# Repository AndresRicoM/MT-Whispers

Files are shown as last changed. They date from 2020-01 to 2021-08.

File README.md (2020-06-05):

# MT-Whispers

```
███╗   ███╗████████╗    ██╗    ██╗██╗  ██╗██╗███████╗██████╗ ███████╗██████╗ ███████╗
████╗ ████║╚══██╔══╝    ██║    ██║██║  ██║██║██╔════╝██╔══██╗██╔════╝██╔══██╗██╔════╝
██╔████╔██║   ██║       ██║ █╗ ██║███████║██║███████╗██████╔╝█████╗  ██████╔╝███████╗
██║╚██╔╝██║   ██║       ██║███╗██║██╔══██║██║╚════██║██╔═══╝ ██╔══╝  ██╔══██╗╚════██║
██║ ╚═╝ ██║   ██║       ╚███╔███╔╝██║  ██║██║███████║██║     ███████╗██║  ██║███████║
╚═╝     ╚═╝   ╚═╝        ╚══╝╚══╝ ╚═╝  ╚═╝╚═╝╚══════╝╚═╝     ╚══════╝╚═╝  ╚═╝╚══════╝
```

Mountain vitals is a project that experiments with a variety of sensors to understand mountain conditions. The project is part of the MIT Media Lab's (City Science Group) collaboration with the country of Andorra.

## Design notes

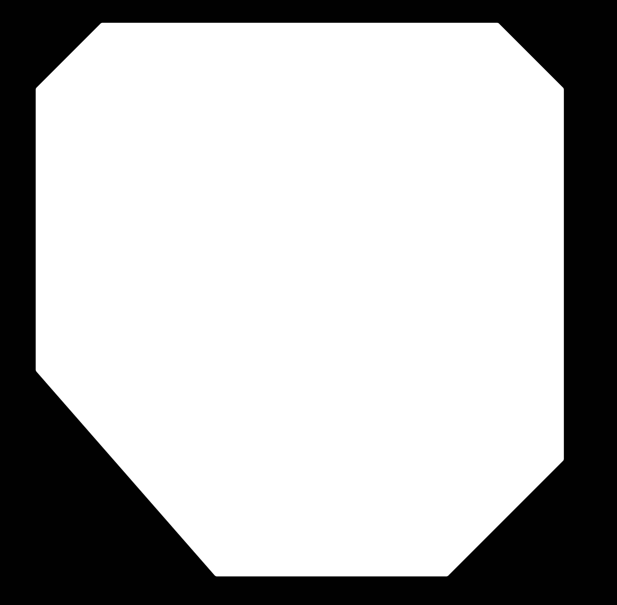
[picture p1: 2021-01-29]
board_production_files/ski-control-v1/ski-control-outline.png

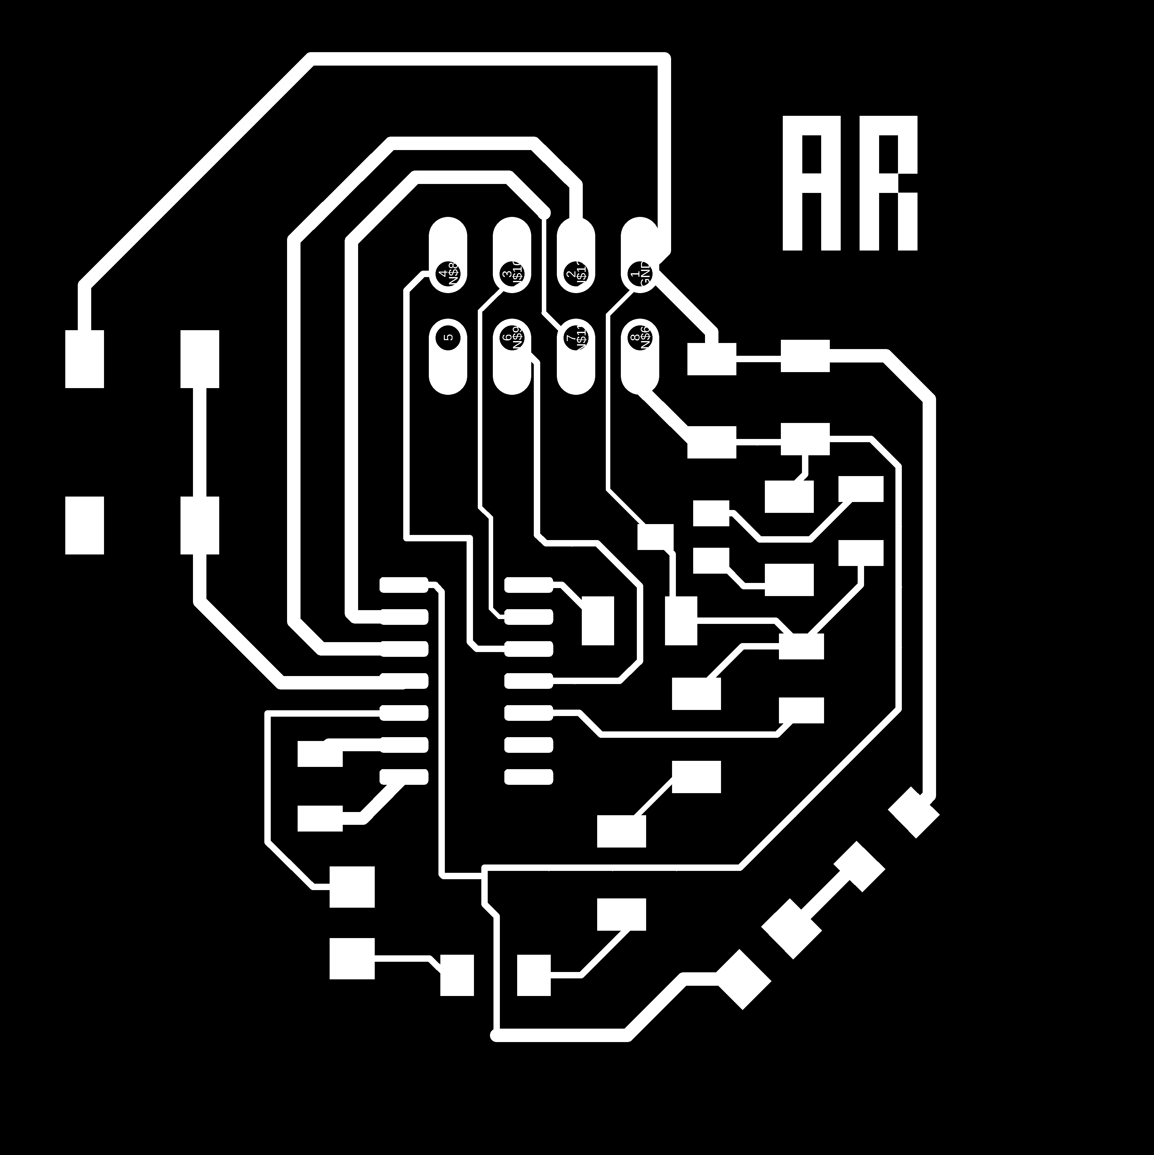
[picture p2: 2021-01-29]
board_production_files/ski-control-v1/ski-control-traces.png

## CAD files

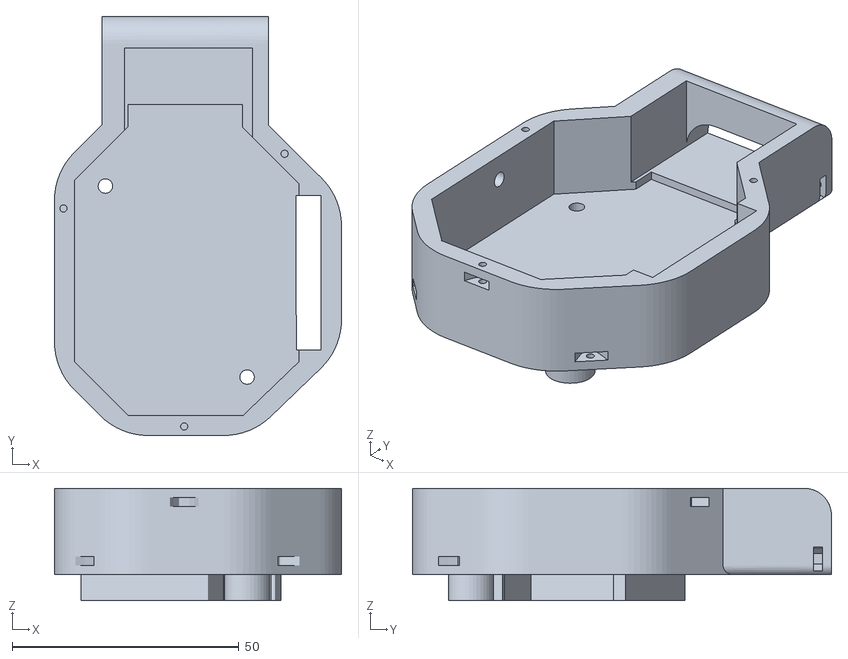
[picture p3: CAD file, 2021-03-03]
part_files/deployment_v1/top_case_therm.stl
63.4 x 92.5 x 24.8

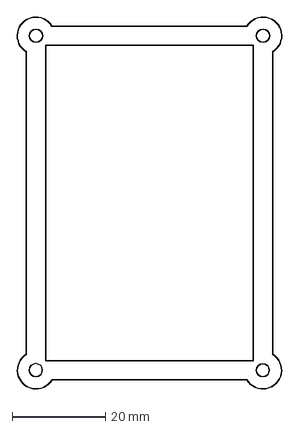
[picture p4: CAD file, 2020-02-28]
part_files/DXF/LM Cover.dxf
57.1 x 80.1 mm

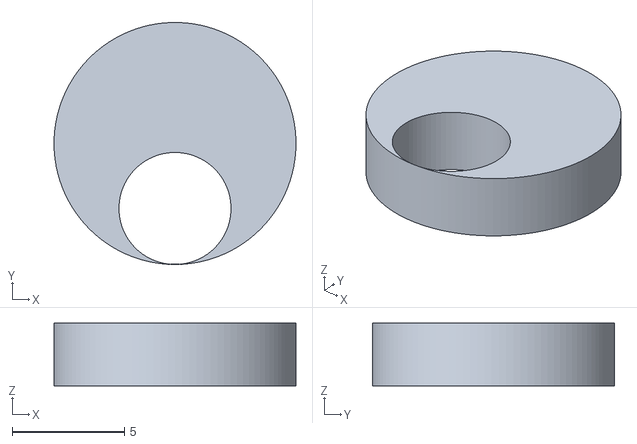
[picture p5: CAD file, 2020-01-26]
part_files/Ski Fix.stl
10.8 x 10.8 x 2.80

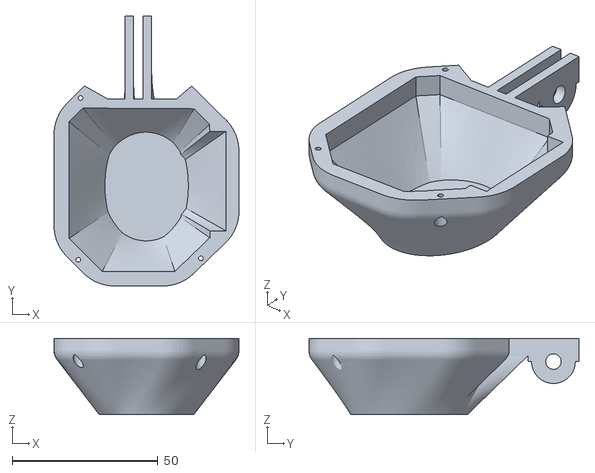
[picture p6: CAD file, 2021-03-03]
part_files/deployment_v1/buttom_case.stl
63.4 x 92.5 x 26.2

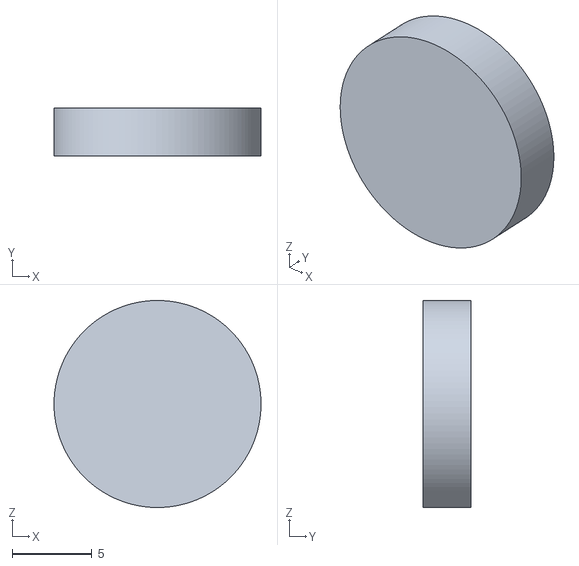
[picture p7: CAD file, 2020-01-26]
part_files/Ski Lid.stl
13.0 x 3.00 x 13.0

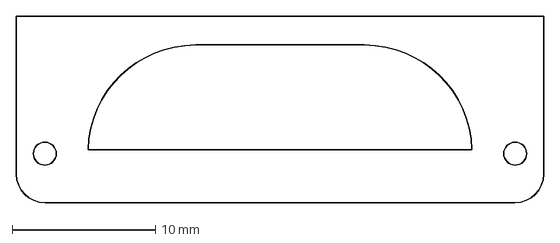
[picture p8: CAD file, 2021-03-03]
part_files/deployment_v1/sd_lid.dxf
36.8 x 13.0 mm

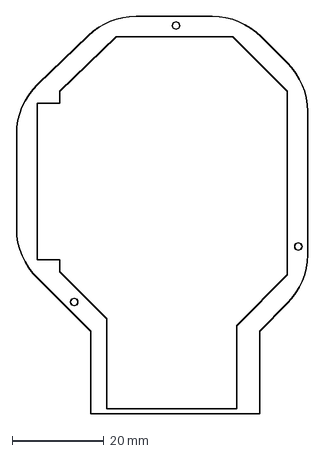
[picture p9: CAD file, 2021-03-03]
part_files/deployment_v1/cover.dxf
63.4 x 86.5 mm

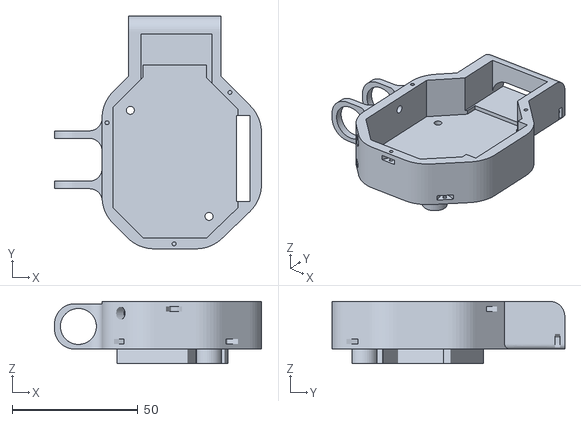
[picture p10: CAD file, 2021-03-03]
part_files/deployment_v1/top_case_digital.stl
82.3 x 92.5 x 24.8

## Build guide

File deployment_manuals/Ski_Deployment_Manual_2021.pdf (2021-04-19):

City Science - ACTUA TECH | Andres Rico 2021 aricom@mit.edu

### Whispers Of The Mountain

Andorra Ski Sensor MARK II Deployment

Main Components

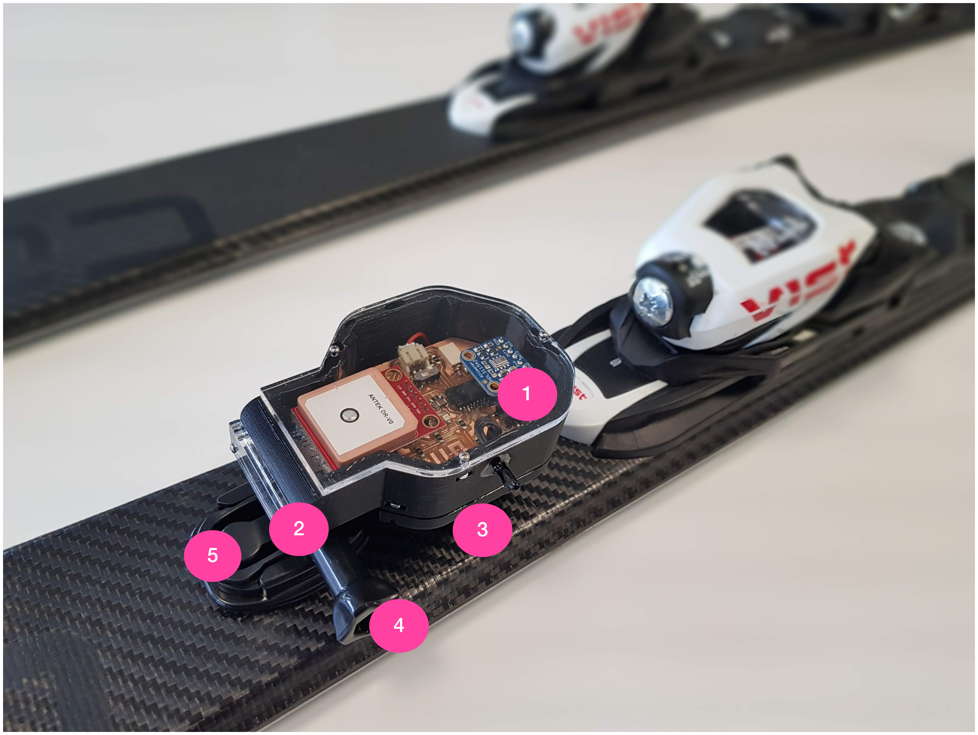
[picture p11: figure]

1. Top Lid - Unmount lid to access ON/OFF switch. WARNING: When mounting and unmounting lid, make sure to not over tighten screws. Screw as far as normal force allows.
2. SD Card Lid / Side Lid - Unmount lid to access SD card. Push SD card to release it from the device. WARNING: When mounting and unmounting lid, make sure to not over tighten screws. Screw as far as normal force allows.
3. Battery Storage - Only unscrew if battery issues arise. Contact Andrés if this happens aricom@mit.edu
4. Mount Screw - Unscrew for mounting onto GoPro gear. When mounted, screw back in, to fix the device and avoid rotations or vibrations.
5. Mount Buckle - Buckle mounts onto adhesive GoPro Mounts. This buckle fits any GoPro accessory. The current model functions best when mounted in front of the ski binding.

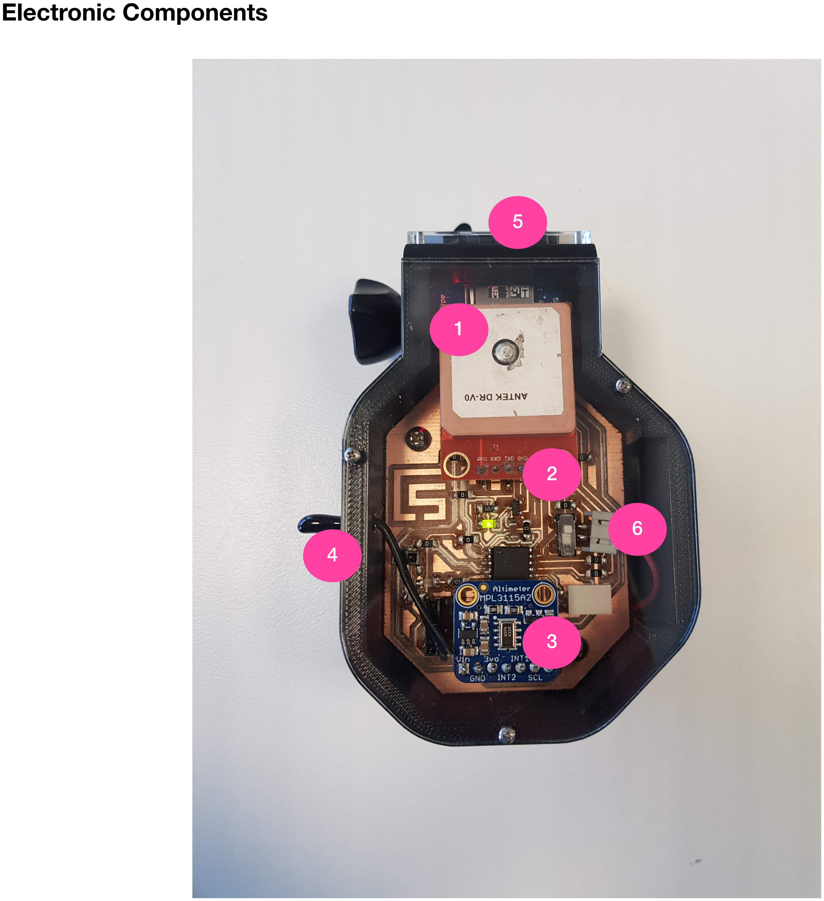
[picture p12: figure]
Electronic Components

1. GPS - Unmountable GPS Module with integrated Antenna.
2. ON/OFF Switch
3. Altimeter/Pressure Sensor - Unmountable Altimeter and Pressure sensor.
4. Temperature Sensor - Epoxy sealed weather resistant NTC temperature sensor.
5. SD Card - MicroSD card mount with push to release capabilities.
6. Battery Jack

LED’s

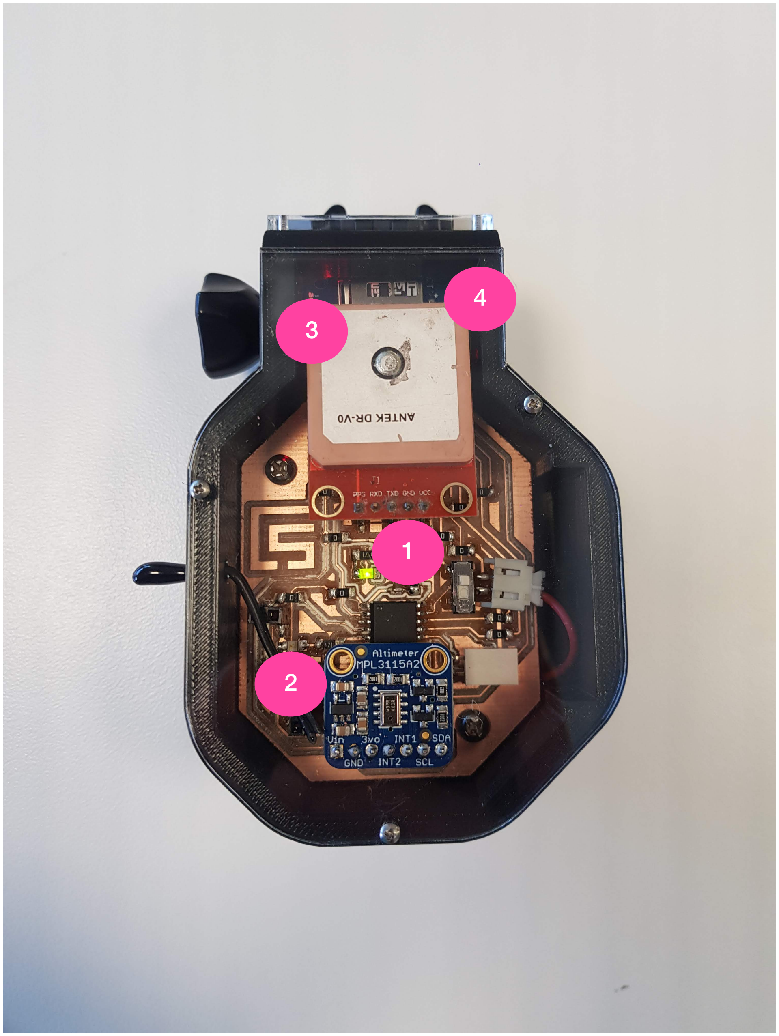
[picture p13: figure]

1. GREEN - ON/OFF - LED will stay ON
2. BLUE - Data Collection - LED will flash when device is turned on and all peripherals were detected correctly.
3. RED - GPS Fix - LED will flash when GPS has connected to satellites. If LED does not flash and just stays ON, it means that GPS has not found any satellites. It will usually take 15 minutes for the GPS to locate the first satellite.
4. RED - SD Card Write - This LED is more visible from the side lid. It will flash whenever data has been correctly saved into the SD cad. If the LED is not flashing it menas that no data is being logged.

Proper operation of the device would have LED 1 on, LED 2 flashing, LED 3 Flashing and LED 4 flashing. If all LEDs have their expected behaviors it means that data is being logged properly and you are set to go.

Data Structure

- File names will be random three number sequences. We will be able to distinguish each data set with the timestamps in the data.
- Sensor will save data into a .txt file. The file can be converted into .csv in the computer.
- Data is structured as follows:

[ Date (month-day-year hour-min-sec-millis), mills (MC Clock in milliseconds), Lat, Lat(N-S), Lon, Lon(E-W), Pressure (Pa), Altitude(meters), Temperature (Celsius) ]

Operation Instructions

- Insert SD Card.
- Unscrew both side lid screws (marked in red). NOTE: The lid might be a bit stuck to the case due to the resin used for waterproofing. If lid does not come off easily you just need to push firmly from the side as indicated by the blue arrow. Make sure to hold the device tightly when pushing so that the lid does not fly off.
- Insert SD card into mount with the SD leads (gold tinted connectors) facing down. you should be able to insert the card without force. Once the card is aligned. Push it in until you hear a click. The mount operates as most GoPro SD Card readers.
- NOTE: To retrieve SD Card you must push and the spring mechanism will eject the card so you can access it and pull it out.

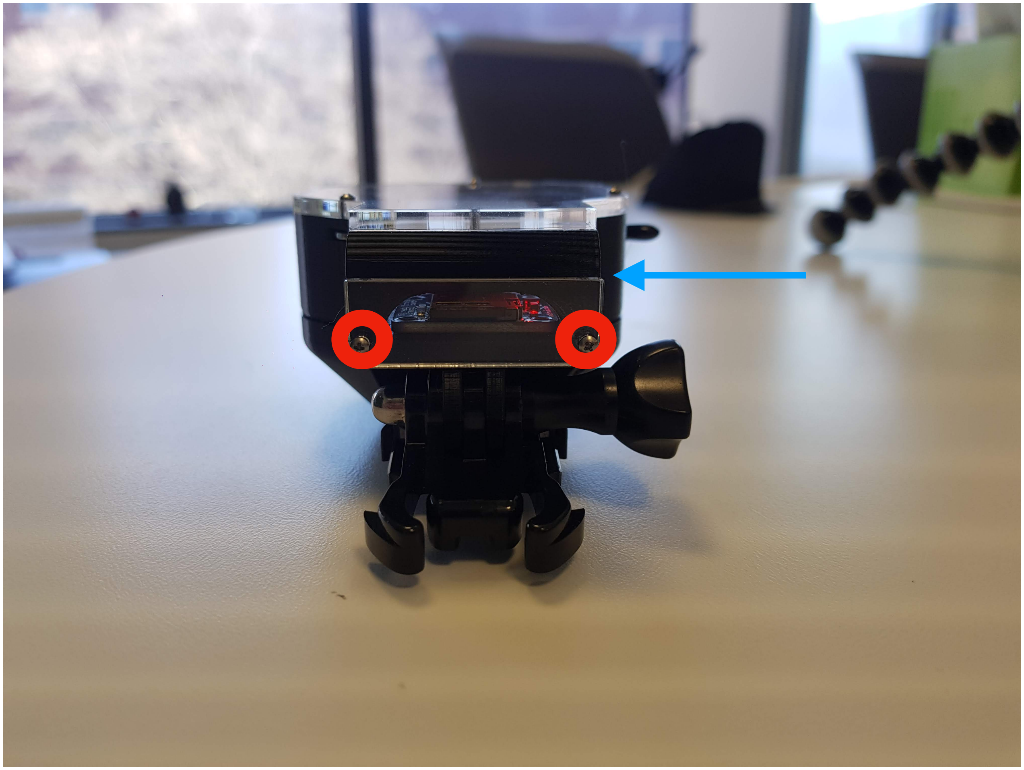
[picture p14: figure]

- Turn Device ON
- Unscrew the three screws (marked in red) from the top lid with a standard philips driver. Be careful with nuts that are located within the casing as they might fall and when unscrewing. NOTE: The lid might be a bit stuck to the case due to the resin used for waterproofing. If lid does not come off easily you just need to push firmly from the side as indicated by the blue arrow. Make sure to hold the device tightly when pushing so that the lid does not fly off.

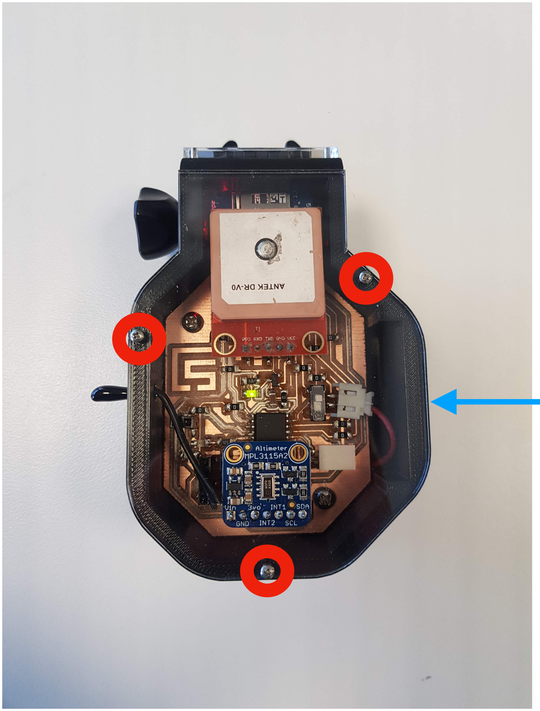
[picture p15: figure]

- Once lid switch the device to the ON state. You should see a green light come ON immediately.
- NOTE: It is highly recommended that the device be turned on at the site of deployment. If turned ON before, battery will be wasted and data that is not related to the mountain or the skis will be saved.
- If everything is connected properly you should see the blue LED blink and then shut off right after turning the device on.
- If everything connects properly, close the lid using the three screws and three nuts. Make sure to not put too much pressure when screwing in the lid so that breaking the edges is avoided.
- Mount Device onto Ski
- Device is mounted using standard GoPro accessories so technically you can mount it into any surface that has a GoPro buckle. For the purpose of this project we will be mounting one of the sensors on a Snow Machine and the other onto a Ski.
- To mount the sensor on a ski we will first adhere the mount (marked in yellow) onto the top of the ski. At a site close to the front binder. Make sure to center the mount (reference picture to see space to leave between mount and ski binder.
- Use the screw (marked in green) to attach the sensor module onto the buckle (marked in red)
- Tighten screw with a philips driver so that any rotation of the device is avoided.

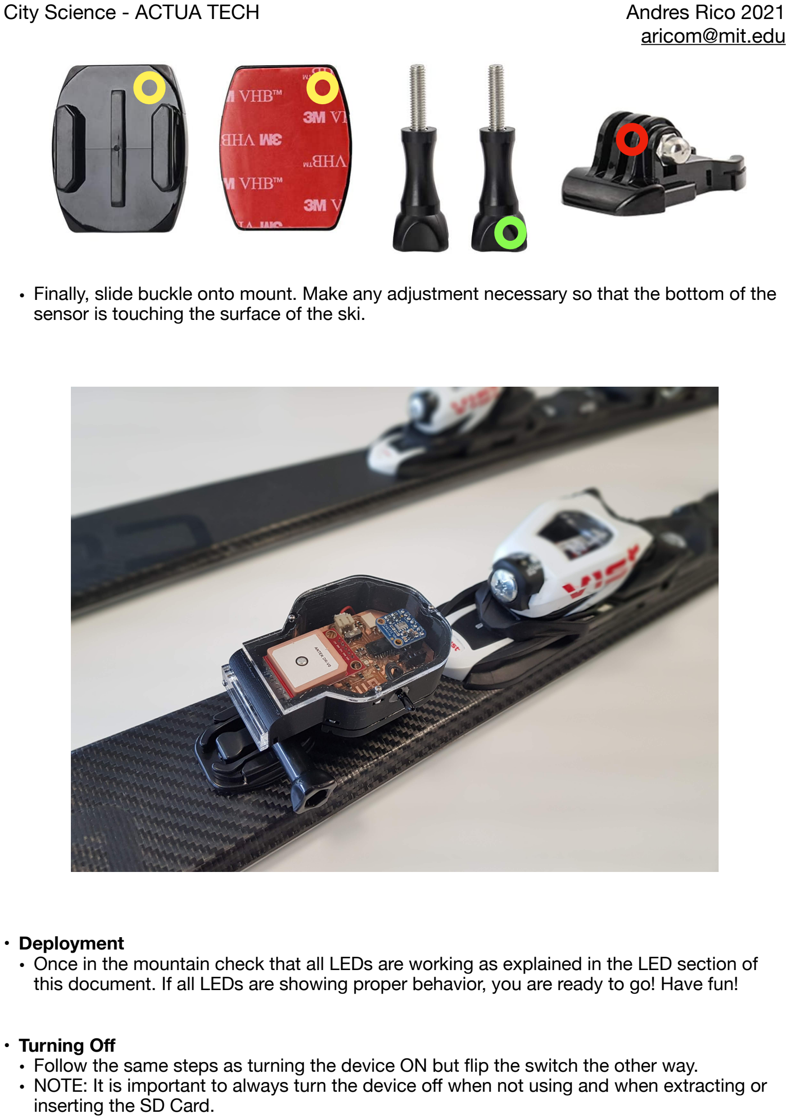
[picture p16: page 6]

- Finally, slide buckle onto mount. Make any adjustment necessary so that the bottom of the sensor is touching the surface of the ski.
- Deployment
- Once in the mountain check that all LEDs are working as explained in the LED section of this document. If all LEDs are showing proper behavior, you are ready to go! Have fun!
- Turning Off
- Follow the same steps as turning the device ON but flip the switch the other way.
- NOTE: It is important to always turn the device off when not using and when extracting or inserting the SD Card.

- NOTE: Battery will give about 6 hours off collection time. Keep good track of the time that the sensor is being used so that you have a good idea of the time left for proper operation.
- Charging Batteries
- If batteries need charging, you must open the device and through the careful use of pliers disconnect the battery. Make sure to be gentle because pulling the battery off can damage the batteries cables and the board. When using pliers make sure to have a good grip on the sections marked in green below.
- It is also advisable to press down with your finger on the battery jack, marked in red. This will help keep the board safe.
- NOTE: One of the boards has a vertical battery jack which makes unplugging the battery much more comfortable and safe.
- WARNING: ALWAYS TURN DEVICE OFF BEFORE EXTRACTING BATTERY.

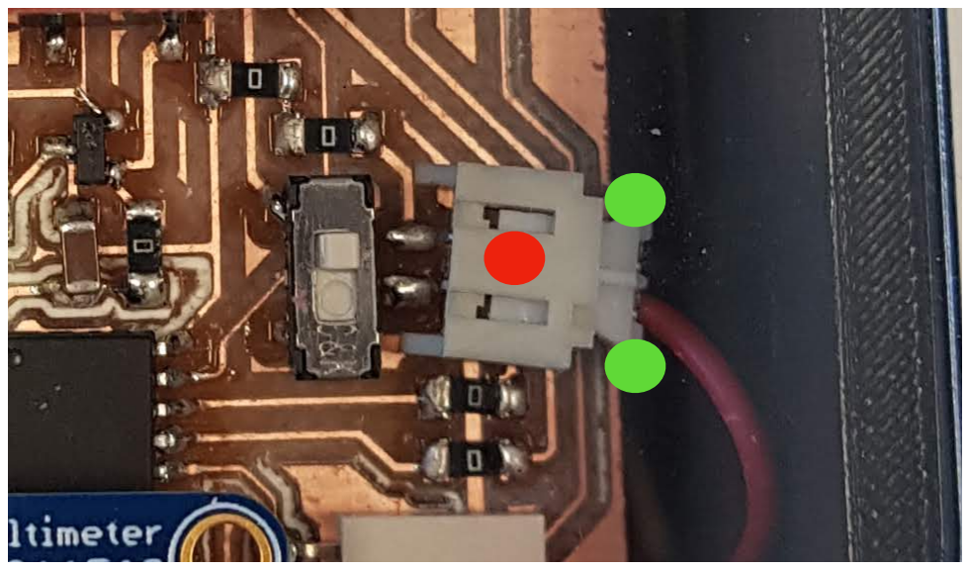
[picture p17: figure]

- Once the battery has been remove, you can plug it into the blue charger supplied within the kit. See image below.
- Connect the white cable to the USB-Wall adapter.
- Connect the mini USB end to the blue chip’s mini USB port (marked in red).
- Connect the LIPO Battery into the battery jack (marked in green).
- NOTE: Battery jacks have a safety plastic slot that avoids mistakes with reversing polarity. If you are plugging in the battery and it does not insert smoothly, you are probably putting it in backwards. Make sure to always plug it in in the correct orientation. Miss-orienting the battery can be dangerous and will kill the boards.

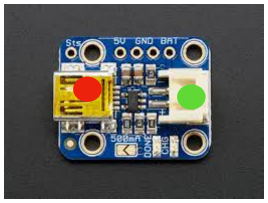
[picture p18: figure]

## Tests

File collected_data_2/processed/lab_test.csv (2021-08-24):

datetime | millis | lat | coordlat | lon | coordlon | pressure | altitude | temp
28-4-2021 13:20:55.070 | 155204 | 42.36032666666667 | N | 71.08373166666668 | W | 101141.50 | 15.06 | 22.42
28-4-2021 13:20:55.070 | 156162 | 42.36032666666667 | N | 71.08373166666668 | W | 101137.75 | 15.44 | 22.34
28-4-2021 13:20:55.070 | 157162 | 42.36032666666667 | N | 71.08373166666668 | W | 101134.50 | 15.56 | 22.34
28-4-2021 13:20:55.070 | 158166 | 42.36032666666667 | N | 71.08373166666668 | W | 101129.00 | 16.12 | 22.34
28-4-2021 13:20:55.070 | 159164 | 42.36032666666667 | N | 71.08373166666668 | W | 101126.75 | 16.06 | 22.34
28-4-2021 13:20:55.070 | 160169 | 42.36032666666667 | N | 71.08373166666668 | W | 101123.75 | 16.12 | 22.34
28-4-2021 13:20:55.070 | 161168 | 42.36032666666667 | N | 71.08373166666668 | W | 101124.50 | 16.50 | 22.34
28-4-2021 13:20:55.070 | 162168 | 42.36032666666667 | N | 71.08373166666668 | W | 101116.25 | 16.75 | 22.42
28-4-2021 13:20:55.070 | 163172 | 42.36032666666667 | N | 71.08373166666668 | W | 101119.00 | 16.81 | 22.42
28-4-2021 13:20:55.070 | 164169 | 42.36032666666667 | N | 71.08373166666668 | W | 101114.25 | 16.87 | 22.42
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

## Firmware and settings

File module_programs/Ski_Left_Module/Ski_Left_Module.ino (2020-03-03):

/*

███████╗██╗  ██╗██╗    ██╗    ██╗██╗  ██╗██╗███████╗██████╗ ███████╗██████╗ ███████╗
██╔════╝██║ ██╔╝██║    ██║    ██║██║  ██║██║██╔════╝██╔══██╗██╔════╝██╔══██╗██╔════╝
███████╗█████╔╝ ██║    ██║ █╗ ██║███████║██║███████╗██████╔╝█████╗  ██████╔╝███████╗
╚════██║██╔═██╗ ██║    ██║███╗██║██╔══██║██║╚════██║██╔═══╝ ██╔══╝  ██╔══██╗╚════██║
███████║██║  ██╗██║    ╚███╔███╔╝██║  ██║██║███████║██║     ███████╗██║  ██║███████║
╚══════╝╚═╝  ╚═╝╚═╝     ╚══╝╚══╝ ╚═╝  ╚═╝╚═╝╚══════╝╚═╝     ╚══════╝╚═╝  ╚═╝╚══════╝
                                                                                    
  Code for right ski data system. The system is based on a adafrut Feather M0 logger Board.
  The system collects data from:
  
  - GPS Module
  - Embedded Capacitive Sensor. 

  Data is stored locally and activation of the device is triggered via RF communication received from the main UI module. 
  
  Andres Rico - MIT Media Lab City Science Group - 2019

*/

#include <SPI.h>
#include <SD.h>

//#include <nRF24L01.h>
#include <RF24.h>

#include <Adafruit_GPS.h>

#include <CapacitiveSensor.h>

#include <Adafruit_NeoPixel.h> //LED Indicator
#ifdef __AVR__
  #include <avr/power.h>
#endif

#define PIN 6 //Pin for LED indicator. 

#define GPSSerial Serial1

#define GPSECHO  false

Adafruit_GPS GPS(&GPSSerial);

RF24 radio(9, 10); // CE, CSN   
const byte addresses [][6] = {"10911", "10917"};
char file_name[6] = "";

uint32_t timer = millis(); //Used for GPS Control. 

bool active_recording = false;
bool active_pin = false;
String flag_moment = "0";

int buttonPin = 5;
int mark_count = 0;

//bool collecting = false; 

File myFile; //Declare file object for using SD library fucntions.
Adafruit_NeoPixel strip = Adafruit_NeoPixel(1, PIN, NEO_GRB + NEO_KHZ800);

float latitude = 0;
float longitude = 0;
String lat, lon;

String filename;

CapacitiveSensor   cs_4_2 = CapacitiveSensor(11,13);

void setup() {

  Serial.begin(115200);

  strip.begin(); //Start LED indicator.

  pinMode(buttonPin, INPUT_PULLUP);

  randomSeed(analogRead(A0));

  Serial.println("Initializing SD Card...");

  if (!SD.begin(4)) {
    Serial.println("SD initialization has failed");
    for (int i = 0; i < 5; i++) {
      strip.setPixelColor(0,255,0,0);
      strip.show();
      delay(200);
      strip.setPixelColor(0,0,0,0);
      strip.show();
      delay(200);
    }
    return;
  }
  Serial.println("SD Initialized!");

  Serial.println("Initializing GPS Communication...");
  GPS.begin(9600); //Start communication with GPS. 
  GPS.sendCommand(PMTK_SET_NMEA_OUTPUT_RMCGGA);
  GPS.sendCommand(PMTK_SET_NMEA_UPDATE_1HZ);
  GPS.sendCommand(PGCMD_ANTENNA);
  Serial.println("GPS Initialized!");

  Serial.println("Initializing Radio Communication...");
  radio.begin();                  //Starting the Wireless communication Radio. 
  radio.openWritingPipe(addresses[0]); //Setting the address where we will send the data
  radio.openReadingPipe(1, addresses[1]);  //Setting the address for receiving data
  radio.setPALevel(RF24_PA_MIN);  //You can set it as minimum or maximum depending on the distance between the transmitter and receiver.
  radio.stopListening();
  Serial.println("Radio Initilized!");

  delay(1000);
  send_rf_cmd("RR");
  delay(200);
  send_rf_cmd("LR");
  delay(500);

   for (int i = 0; i < 5; i++) { //Blink in white to show success. 
    
      strip.setPixelColor(0,255,255,255);
      strip.show();
      delay(200);
      strip.setPixelColor(0,0,0,0);
      strip.show();
      delay(200);
      
    }

  strip.setPixelColor(0,0,255,255);
  strip.show();
  Serial.println("Ready to Start!");
  
}

void loop() {

  if (!active_recording) {
    check_radio_activation();
    check_pin();
  }

  if (active_pin) {
    
    String prand = String(random(100,999));
    file_name[0] = prand [0];
    file_name[1] = prand [1];
    file_name[2] = prand [2];
    file_name[3] = '.';
    file_name[4] = 't';
    file_name[5] = 'x';
    file_name[6] = 't';
    myFile = SD.open(file_name, FILE_WRITE);    
    Serial.println("RECORDING DATA");
    strip.setPixelColor(0,255,0,0);
    strip.show();
    Serial.flush();
    
  }
  
  if (active_recording && !active_pin) {
    radio.startListening();
    char incoming[4] = ""; 

    Serial.println("Waiting for file name...");
    
    while (!radio.available());
      
    radio.read(&incoming, sizeof(incoming)); //Read file name. 
    Serial.println(incoming);
    
    file_name[0] = incoming [0];
    file_name[1] = incoming [1];
    file_name[2] = incoming [2];
    file_name[3] = '.';
    file_name[4] = 't';
    file_name[5] = 'x';
    file_name[6] = 't';
    
    Serial.println(file_name);

    myFile = SD.open(file_name, FILE_WRITE);
    
    //radio.stopListening();
    Serial.println("Received file name!");
  
    Serial.println("RECORDING DATA");
    strip.setPixelColor(0,255,0,0);
    strip.show();
    Serial.flush();
      
  }

  while (active_recording) {

    strip.setPixelColor(0,255,0,0);
    strip.show();
    
    //Serial.println("I am here");
    char c = GPS.read();
    //Serial.println(c);
    if (GPS.newNMEAreceived()) {
  
      if (!GPS.parse(GPS.lastNMEA()));
        //Serial.println("I WILL RETURN!");   
        //return; 
    }
  
    if (timer > millis())  timer = millis(); //Reset timer if it wraps. 
  
    if (millis() - timer > 25) { //Prints out current information every 25 milliseconds. 
      
      timer = millis(); // reset the timer

  
      if (GPS.fix) {
        //Serial.println("I have fix");
        strip.setPixelColor(0,0,255,0);
        strip.show();
 
        long start = millis();
        long total1 =  cs_4_2.capacitiveSensor(30);

        //Serial.println(total1);
        
        latitude = (GPS.latitude);
        longitude = (GPS.longitude);
        lat = GPS.lat;
        lon = GPS.lon;

        if (mark_count > 10) {
          flag_moment = "0";
        }
        
        if (flag_moment == "1") {
          mark_count = mark_count + 1;
        }

        Serial.print(millis()); Serial.print(",");
        Serial.print(latitude, 4); Serial.print(",");
        Serial.print(lat); Serial.print(",");
        Serial.print(longitude, 4); Serial.print(",");
        Serial.print(lon); Serial.print(",");
        Serial.print (total1); Serial.print(",");
        Serial.println(flag_moment);

        
        myFile = SD.open(file_name, FILE_WRITE);

        myFile.print(millis()); myFile.print(",");
        myFile.print(latitude, 4); myFile.print(",");
        myFile.print(lat); myFile.print(",");
        myFile.print(longitude, 4); myFile.print(",");
        myFile.print(lon); myFile.print(",");
        myFile.print (total1); myFile.print(",");
        myFile.println (flag_moment);

        myFile.close();

        strip.setPixelColor(0,0,0,0);
        strip.show();
                
      } 
      
    }
    
    check_radio_activation();
    check_pin();
    
  }

  strip.setPixelColor(0,0,255,255);
  strip.show();
  myFile.close();
  
}

void print_radio() {
  
  radio.startListening();

  if (radio.available()) {                      //Looking for the data.{
      
      char incoming[4] = "";                      //Saving the incoming data
      radio.read(&incoming, sizeof(incoming));    //Reading the data
      Serial.println(incoming);
  
      delay(200);
      send_rf_cmd("RR");
      delay(100);
      send_rf_cmd("LR");

    }
}

void send_rf_cmd(String message) { //Function sends a command via radio. Takes string as argument and converts to char to send. 

  char mess[4] = "000";
  strcpy(mess, message.c_str());
  Serial.println(mess);
  radio.stopListening();
  radio.write(&mess, sizeof(mess));
  
}

void check_pin() {
  //Serial.println(digitalRead(buttonPin));
  if (!digitalRead(buttonPin)) {
    if (!active_recording) {
      active_recording = true;
      active_pin = true;
      Serial.println("Acivation By Buuton");
      delay(350);
    } else if (active_recording) {
      active_recording = false;
      active_pin = false;
      Serial.println("Stoped With Button");
      delay(350);
    }
  }
}

void check_radio_activation() {
  radio.startListening();
  
  if (radio.available()) {
    
    char incoming[3] = ""; 

    radio.read(&incoming, sizeof(incoming));
    Serial.println(incoming);
    delay(200);
    
    
    if (incoming[0] == 'B' && incoming[1] == 'R') {
      
      active_recording = true; 
      Serial.println("Recording Has Been Activated");
    } 

    if (incoming[0] == 'E' && incoming[1] == 'R') {
      
      active_recording = false; 
      Serial.println("Recording Has Been Deactivated");
    }

    if (incoming[0] == 'F' && incoming[1] == 'M') {
      mark_count = 0;
      flag_moment = "1";
    }
  } 
}

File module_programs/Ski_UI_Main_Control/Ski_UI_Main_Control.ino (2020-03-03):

/*

███████╗██╗  ██╗██╗    ██╗    ██╗██╗  ██╗██╗███████╗██████╗ ███████╗██████╗ ███████╗
██╔════╝██║ ██╔╝██║    ██║    ██║██║  ██║██║██╔════╝██╔══██╗██╔════╝██╔══██╗██╔════╝
███████╗█████╔╝ ██║    ██║ █╗ ██║███████║██║███████╗██████╔╝█████╗  ██████╔╝███████╗
╚════██║██╔═██╗ ██║    ██║███╗██║██╔══██║██║╚════██║██╔═══╝ ██╔══╝  ██╔══██╗╚════██║
███████║██║  ██╗██║    ╚███╔███╔╝██║  ██║██║███████║██║     ███████╗██║  ██║███████║
╚══════╝╚═╝  ╚═╝╚═╝     ╚══╝╚══╝ ╚═╝  ╚═╝╚═╝╚══════╝╚═╝     ╚══════╝╚═╝  ╚═╝╚══════╝
                                                                                    
  Main code for Ski UI. The UI is responsible for controlling both ski modules. 
  It receives voice commands through voice shield, activates the visual fiber optic display
  and send commands to modules via RF.

  File name and flags are set by the main UI. 
    
  Andres Rico - MIT Media Lab City Science Group - 2019

*/

#include <SPI.h>
#include <SD.h>
//#include <nRF24L01.h>
#include <RF24.h>
#include <Adafruit_NeoPixel.h>
#ifdef __AVR__
  #include <avr/power.h>
#endif

#define PIN 6 //8 Teensy

int pixel_num = 1;

RF24 radio(9, 10); // CE, CSN (9,5) Teensy

Adafruit_NeoPixel strip = Adafruit_NeoPixel(pixel_num, PIN, NEO_GRB + NEO_KHZ800);

const byte addresses [][6] = {"10911", "10917"}; // MSN, MSG 

int button_pin = 2; //2 - 5
boolean button_state = 0;
bool stuck = false;
unsigned long start_time, block_time;
bool collecting = false;

byte audio = 0;
int voice_state = 0;


void setup() {
  
  Serial.begin(115200);
  Serial1.begin(9600); //Serial for voice interface. 

  Serial.println("Setting up voice interface");
  delay(2000);
  Serial1.write(0xAA);
  Serial1.write(0x37);
  delay(1000);
  Serial1.write(0xAA);
  Serial1.write(0x21);
  Serial.println("Finished setting up interface!");

  pinMode(button_pin, INPUT_PULLUP);

  randomSeed(analogRead(A0));

  radio.begin();
  radio.openWritingPipe(addresses[1]);
  radio.openReadingPipe(1, addresses[0]);      
  radio.setPALevel(RF24_PA_MIN);
  radio.startListening();  

  strip.begin();
  strip.show();

  Serial.println("Connecting to external modules...");
  //start_radio();
  /*all_lights_on(255,0,0);
  delay(1000);
  all_lights_on(0,255,0);
  delay(1000);
  all_lights_on(0,0,255);
  delay(1000);
  rainbow(15);
  delay(1000);*/
  all_lights_on(0,255,255);
  delay(100);
  Serial.println("Ready to begin!");
  
}

void loop() {

  
  if (Serial1.available()) {
    rainbow(10);
    audio = Serial1.read();
    Serial.println(audio);
  }

  voice_select();
  button_state = digitalRead(button_pin); //This will be changed to voice commands.
  
  if (voice_state == 4) {
    send_rf_cmd("FM");
    delay(300);

    for (int i = 0; i < 5 ; i++) {
      all_lights_on(0,255,0);
      delay(200);
      all_lights_off();
      delay(100);
    }
    all_lights_on(255,0,0);
    voice_state = 0;
    
  }
  
  if ((!button_state || voice_state == 2)  && !collecting) {

    collecting = true;
    
    send_rf_cmd("BR");
        
    String new_code = new_file_name();
    delay(400);
    //unfailable_send(new_code);
    for (int i = 0; i < 5; i++) {
      send_rf_cmd(new_code);
    }
    //send_rf_cmd(new_code);
    //delay(500);
    for (int i = 0; i < 5 ; i++) {
      all_lights_on(0,255,0);
      delay(200);
      all_lights_off();
      delay(100);
    }
    all_lights_on(255,0,0);
  }

  button_state = digitalRead(button_pin);
  //Serial.println(button_state);

  if ((!button_state || voice_state == 3)  && collecting) {
    collecting = false;

    //all_lights_on(0,255,255);

    //unfailable_send("ER");//End Recording
    for (int i = 0; i < 5; i++) {
      send_rf_cmd("ER");
      delay(10);
    }
    //String new_code = new_file_name();
    delay(300);
    //unfailable_send(new_code);
    //delay(500);
    for (int i = 0; i < 5 ; i++) {
      all_lights_on(0,255,0);
      delay(200);
      all_lights_off();
      delay(100);
    }
    all_lights_on(0,255,255);
  }
  
}

void start_radio() { //Function listens to find left and right modules. 
  
  bool right_connected = false;
  bool left_connected = false;
  char incoming[3] = ""; 

  radio.startListening();
  Serial.println(radio.available());

  while(!radio.available()); //Waits until new message is received. 
  
  radio.read(&incoming, sizeof(incoming));
  Serial.println(incoming);
  
  if (incoming[0] == 'R' && incoming[1] == 'R') {
    
    right_connected = true; 
    Serial.println("Right Radio Is Connected");
  
  } 

  if (incoming[0] == 'L' && incoming[1] == 'R') {
    
    left_connected = true; 
    Serial.println("Left Radio Is Connected");
    
  }

  while(!radio.available()); //Waits until new message is received. 

  radio.read(&incoming, sizeof(incoming)); 
  Serial.println(incoming);

  if (incoming[0] == 'R' && incoming[1] == 'R') {
    
    right_connected = true; 
    Serial.println("Right Radio Is Connected");
  
  } 

  if (incoming[0] == 'L' && incoming[1] == 'R') {
    
    left_connected = true; 
    Serial.println("Left Radio Is Connected");
  
  }

  if (right_connected && left_connected) {
    Serial.println("RF connection has been made!");
    //Add LED signal. 
  } else {
    Serial.println("Not Connected.");
    
  }
  
}

String new_file_name() { //Function creates a new random name to write on module files. 
  
  long random_number = random(100,999);
  String file_code = String(random_number);
  return  file_code;
  
}

void send_rf_cmd(String message) { //Function sends a command via radio. Takes string as argument and converts to char to send. 

  char mess[4] = "000";
  strcpy(mess, message.c_str());
  Serial.println(mess);
  radio.stopListening();
  radio.write(&mess, sizeof(mess));
  
}


bool confirm_rf(String conf_mess) { //Boolean function to confrim if RF was received by slave module. Takes a wanted string as argument. 
  
  char confirmation[4] = "000";
  
  strcpy(confirmation, conf_mess.c_str());
  
  radio.startListening();

  if (radio.available()) {

    char in[4] = "";
    radio.read(&in, sizeof(in));
    //Serial.println(in);
  
    if (in[0] == confirmation[0] && in[1] == confirmation[1]) {
      
      //Serial.println("Message has been correctly delivered by Radio");
      return true;
    }
    
  }
}

bool timed_check(String confirm_string) { //Checks that sent command has been received and adds timeout break. 

  start_time = millis();
    
    while (!confirm_rf(confirm_string) && !stuck) { //Confirms that both modules have received the file name.
      
      block_time = millis() - start_time;
      
      if (block_time >= 500) {
        Serial.println("Response Time Exceeded");
        stuck = true;
      }
    }

    if (stuck) {
      Serial.print("Did not receive confirmation from: ");
      Serial.println(confirm_string);
      //////////WILL NEED TO ADD IF STATEMENT FOR INDICATING WHICH MODULE FAILED.
    }  
}
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

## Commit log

2019-11-22 Add files via upload
    First iteration of digital ski collector. Can collect 9 axis IMU values + temperature + humidity.
2020-01-26 New repo structure and data
    [807_SKI 2.csv, Capacitive Test Analysis.xlsx, Ski Fix.stl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]
2020-01-26 CSV data files
    [1.csv, 2.csv, 3.csv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]
2020-01-30 GPS Data Processing
    [3.csv, 4.csv, 5.csv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]
2020-02-12 Interpolation added.
    [test.csv]
2020-02-13 Fixing GPS & Merge
    [1.csv, 2.csv, 3.csv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]
2020-02-14 Iterative Merginf for multiple files
    [1.csv, 2.csv, 3.csv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]
2020-02-14 Good gps is good.
    [interpolated.csv]
2020-02-28 Filtered Zeros, still need to fix one set...
    [1.csv, 2.csv, 3.csv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]
2020-02-28 Adding DXF files
    [LM Cover.dxf]
2020-03-04 New Data
    [147.csv, 215.csv, 216.csv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]
2020-03-05 fixed data cleaning
    [147.csv, 215.csv, 293.csv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]
2020-03-10 automation for processing data
    [147.csv, 215.csv, 216.csv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]
2020-03-24 Car tests Metepec
    [207.csv, 301.csv, 553.csv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]
2020-03-24 Auto Process Added
    [1.csv, 147.csv, 2.csv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]
2020-03-24 Tested automation
    [301.csv]
2020-03-26 fft analysis fixed
    [884.csv]
2020-04-06 New Test Data
    [102.csv, 154.csv, 202.csv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]
2021-01-29 board priduction files
2021-03-03 new part files for first deployment
    [buttom_case.stl, cover.dxf, sd_lid.dxf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]
2021-03-11 added printing gcode for prusa mvp1
2021-04-19 added remote data
    [ski1_andorra_D1.csv]
2021-04-19 andorra test visuals
    [ski1_andorra_D1.csv]
2021-08-24 added porto and lisbon data
    [lab_test.csv, porto.csv]
